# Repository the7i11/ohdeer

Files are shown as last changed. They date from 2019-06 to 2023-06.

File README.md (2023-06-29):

# Oh Deer!

A non-profit and open source project, with the goal to develop a device to frighten deer and other ferral animals.

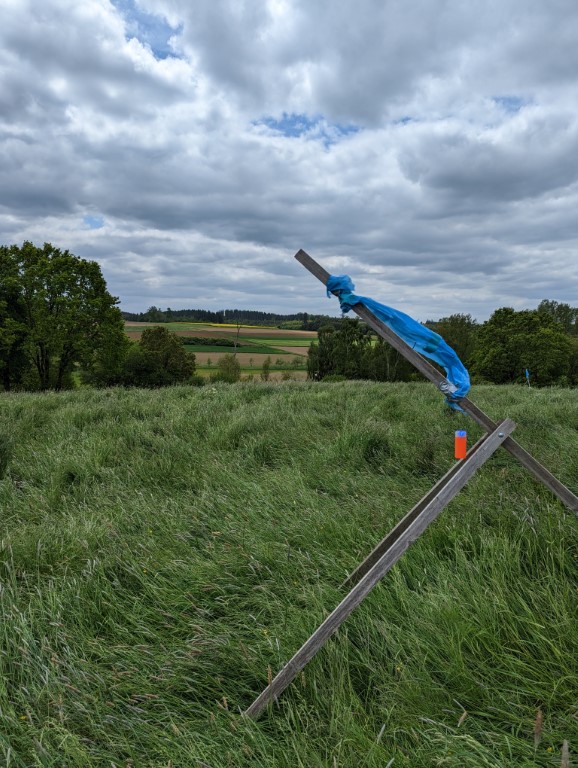
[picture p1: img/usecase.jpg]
Use case


## About this project

Every spring, usually around May, deer will give birth to their fawns. Still not being able to run away from potential predators, those fawns will rely on their camouflage and remarkable abscence of any kind of scent to survive. Early in the morning, still before sunrise, their mothers will lay them down in high grass, where they hopefully won't be discovered, to pick them up again at dawn.

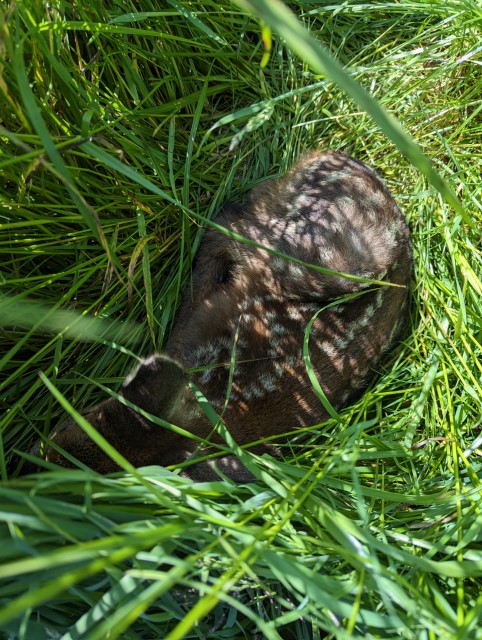
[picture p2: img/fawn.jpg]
Fawn in grass


Unfortunately, this time of the year does overlap with farmers having to mow their meadows. As you might guess, the tractor does not really care about good camouflage at all - so when the fawns will instinctively just put their head down, being mowed over will result in certain death.

Of course, farmers are obligers to take precautions, but if only half of all farmers would actually take what is required, the [...]
At least in Germany, hunters will support the farmers to prevent fawns from death by mower, sometimes by taking multiple precautions. Hunters will walk through the meadows in tight grids, fly over them using drones and thermal imaging technology and (that's what this project is about) take measures so the deer won't put their fawns in the grass in the first place.

Taking a commercial product as an example, we developed a device, that is placed in the meadows the day befor the farmer want's to mow it. The loud beeping and random, bright, blue blinking of the device will (hopefully) scare mother deer so much, that they won't put their fawns in this field specifically.

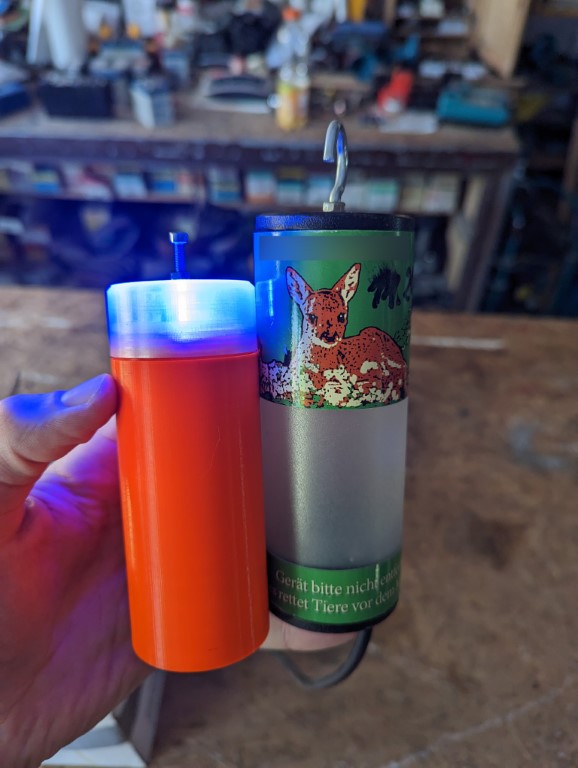
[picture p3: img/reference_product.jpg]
Oh deer


The reference product that we used for the past years did cover our needs, but was way to expensive for the ammount we required. For larger meadows, you'll need around 10-15 of those tubes, costing a hefty four-digit ammount of money that we have to largely pay out of our own pockets. 

This is why we started to develop our own, low-cost variant of this. Apart from you having to assemble it manually, we do have many advantages over the commercial one:

- Being open source means you can modify it to fit your specific needs
- We come in at less than a tenth of the price of the commercial one
- The conveniance in handeling of Oh Deer is far higher, mostly because of the integrated battery/charger
- The LED is way brighter and does have a seemingly random pattern
- In our next iteration, the buzzer will be much louder, covering a higher radius

In case you want to build your own devices from this, you should find everything required within this repository.

## First / Second iteration

As a first draft, I developed the project around the STM8F103 microcontroller. Back in the day, it way readily available and cheap. 
The second iteration will be using a Risc V controller from CHT (CH32V003), which has become famous for being one of the cheapest general-purpose µCs there is.

## Getting started

To actually build the devices on your own / contribute to the project, please follow the guides for each HW iteration:

- [1. Iteration](doc/1.0_Getting_Started.md)
- [1. Iteration](doc/2.0_Getting_Started.md)

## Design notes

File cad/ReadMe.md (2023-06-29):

# 3D-Printed Case

For the sake of simplicity, the case is coming directly out of a 3D-Printer.
If you don't have one on you own, you might wan't to ask someone who does.
As with the other hardware, I (currently) cannot provide them to anyone I don't know personally.

## How to print

Printing in PETG will generally have a higher weather resistance than PLA. However, PLA will not immediately dissolve in rain - it can withstand even more than a year ouside without turning into compost.

### Lid

- `lid.stl`
- Printed transparently
- Extrusion factor bumped up by 3%-5% (better transparency)

### Base Case

- `base_case.stl`
- Printed in bright orange to be easily visible in the green grass

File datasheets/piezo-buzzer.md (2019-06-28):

# Available data

- 3-24 V
- Alarm Durchmesser: 22mm/0,86"
- Alarm Höhe: 10mm/0,39”
- 2 montage Löcher abstand: 30mm/1,18"
- 2 drähte länge: 90mm/3,54"
- Summer Typ: Piezoelektrischen
- Schalldruckpegel 95 dB
- Rate Spannung: 12 V DC
- Betriebs Spannung: 3-24 V
- Max Strom Bewertung 10mA
- Frequenz 3900±500Hz
- Stick Methode: Stick Schaltung Gebaut in Montage Löcher
- Sound: "Di" Kontinuierliche

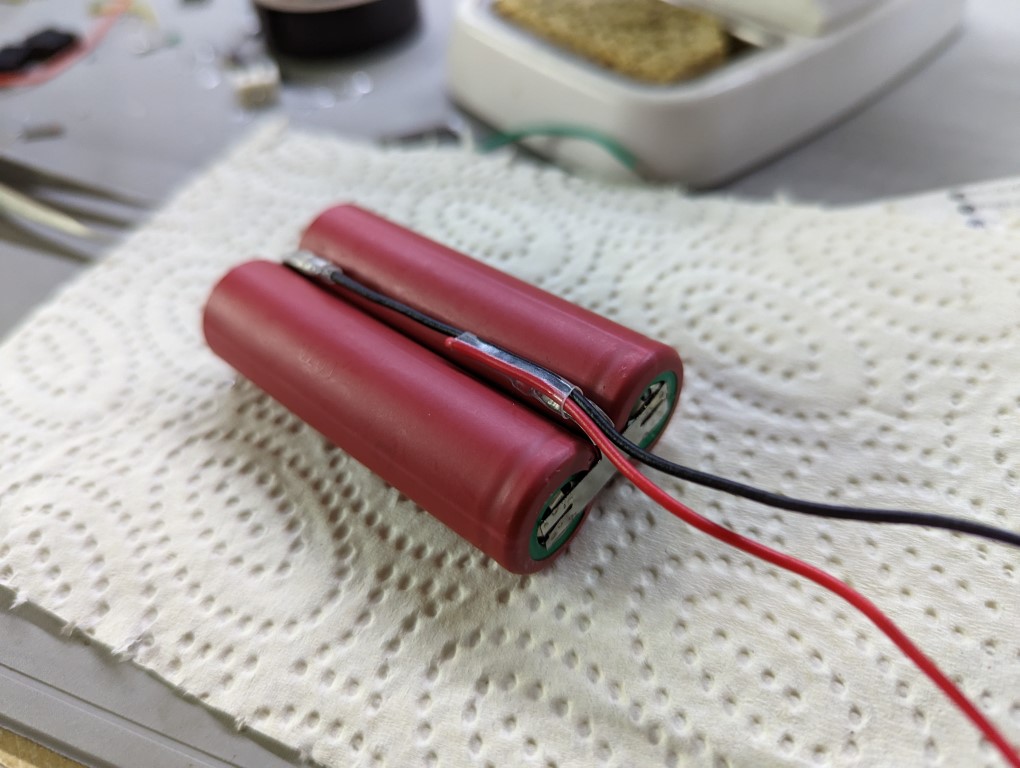
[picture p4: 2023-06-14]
img/battery_pack.jpg

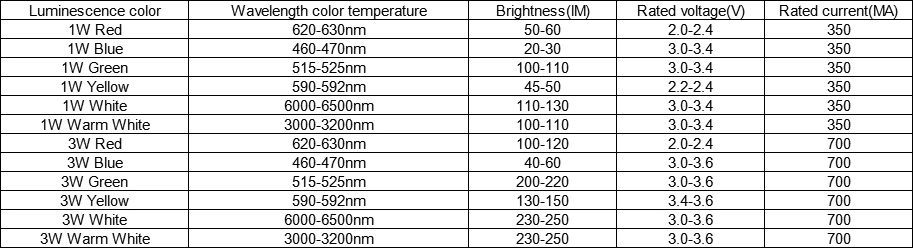
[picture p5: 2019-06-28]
datasheets/LED-2.webp

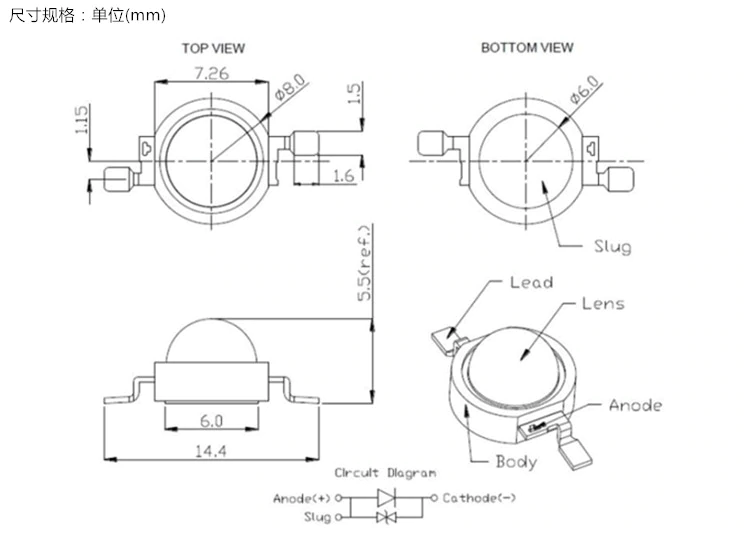
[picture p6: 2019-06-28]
datasheets/LED-1.webp

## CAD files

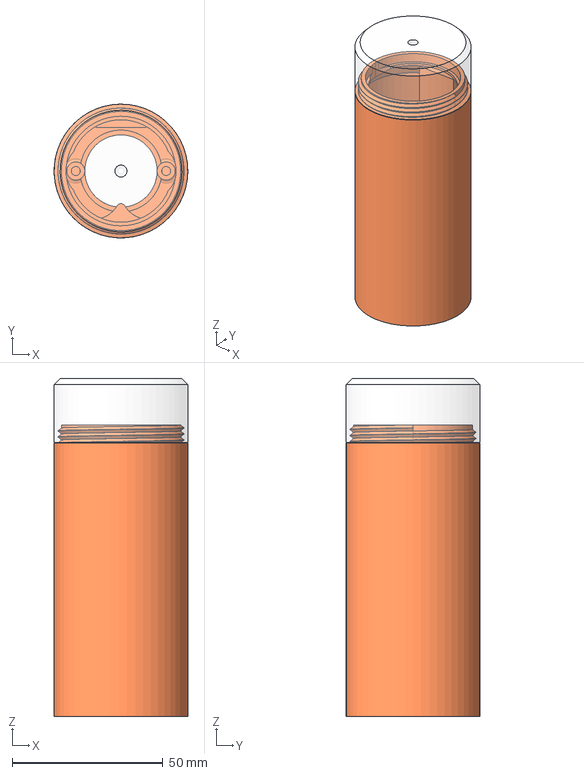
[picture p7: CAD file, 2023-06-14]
cad/base_case.FCStd
44.4 x 44.4 x 112.2 mm
case
Lid

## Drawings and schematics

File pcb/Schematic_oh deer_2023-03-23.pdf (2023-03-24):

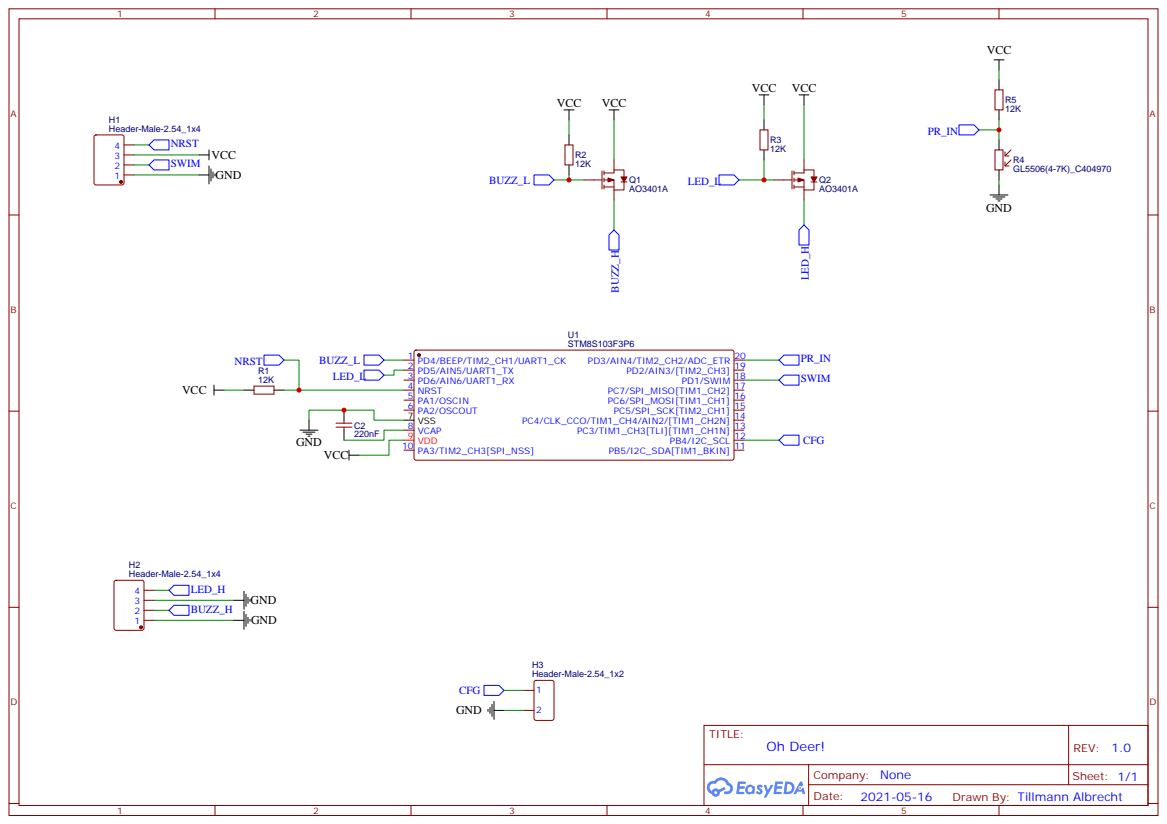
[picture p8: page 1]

Drawn By: Tillmann Albrecht

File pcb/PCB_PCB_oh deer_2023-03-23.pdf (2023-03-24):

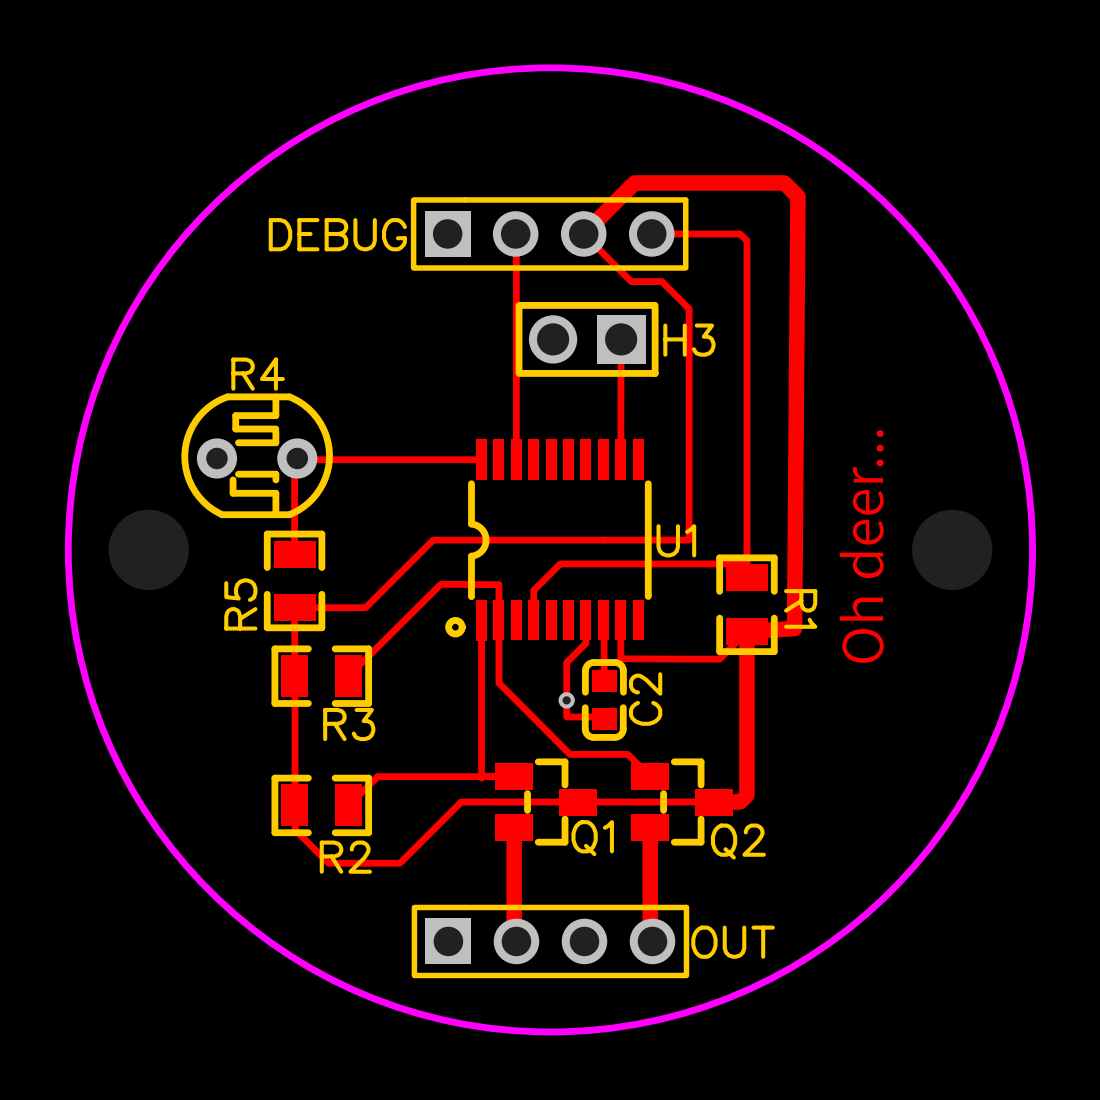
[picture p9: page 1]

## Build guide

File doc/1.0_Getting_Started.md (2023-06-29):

# Getting Started - First iteration

## Hardware requirements

- [PCB](https://oshwlab.com/tillmann95/oh-deer)
- [ST-Link V2](https://www.st.com/en/development-tools/st-link-v2.html) (or Mini) + 4 Socket-to-Socket Jumper cables
- [3D printed Case](../cad/ReadMe.md)
- 1 - 2 Generic 18650 (Li-Ion) cells
- _(optional)_ A spot welder & some nickle strips
- [Battery Protection module](https://www.reichelt.de/entwicklerboards-ladeplatine-fuer-3-7v-li-akkus-usb-c-1a-debo1-3-7li-1-0a-p291398.html)
- Piezo buzzer
- Some generic M3 screws for assembly

## Software requirements

- Visual Studio Code
- PlatformIO plugin for VS Code
- ST-Link drivers

## PCB Assembly

- Do detailed assembly guide yet
- Figure this out on your own using the [PCB drawing](../pcb/PCB_PCB_oh%20deer_2023-03-23.pdf) and [circuit schematic](../pcb/Schematic_oh%20deer_2023-03-23.pdf)

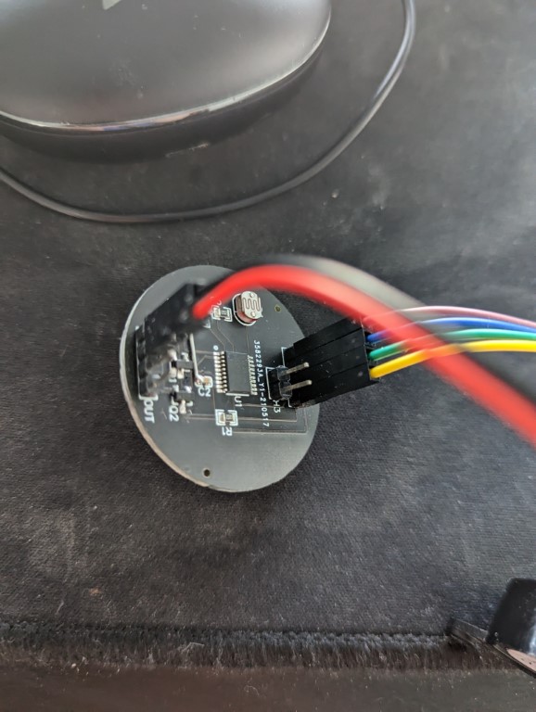
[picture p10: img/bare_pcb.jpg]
bare pcb


## Preparing the flashing/debugging

Connect the following pins from the ST-Link V2 to the PCB. You should find their labels on the device/PCB:

- GND
- SWIM
- RST
- 3V3 (or 5V, both will work)

By using 3V3, the buzzer is somewhat easier to bear during development. Even taping it shut will only dampen the noise so a somewhat bearable level.

## Compiling & FW download

After opening this project in PlatformIO, you can just hit the "Upload" button from inside PlatformIO. Now the device should already be blinking & beeping.

## Mounting the buzzer

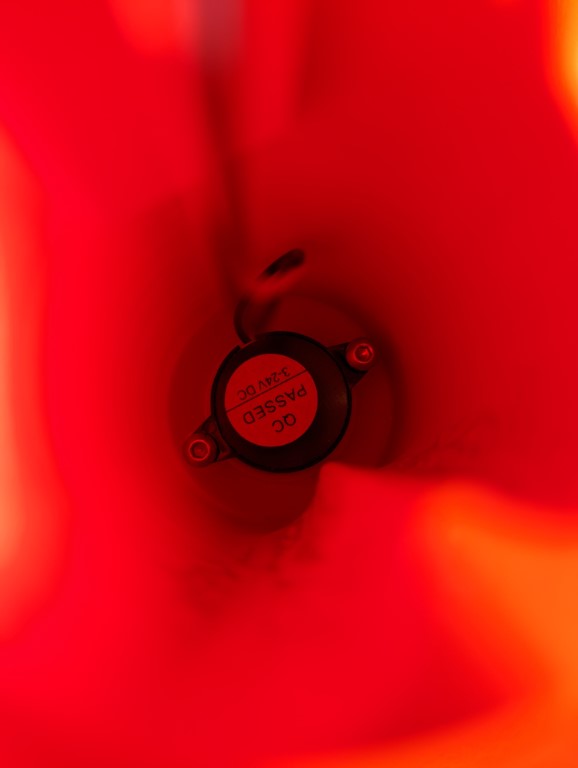
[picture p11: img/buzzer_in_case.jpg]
Buzzer in case


The buzzer gets screwed in using M3  screws (5mm - 8mm length).

This can be a bit fiddly. If you bend the wires straight before inserting, you might have an easier time.

## _(optional)_ Battery pack assembly

The _proper_ way to connect 18650 cells to a pack and connect wires to them is using a spot welder:

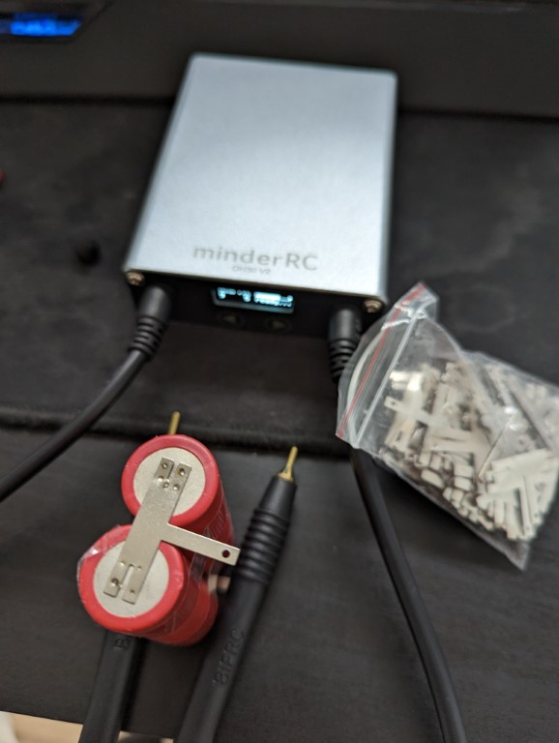
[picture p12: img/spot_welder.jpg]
spot welder


This makes sure that the delicate cells don't overheat and explode. _It is possible_ to solder directly to the pads, but it's a pain in the ass and I can only **strongly** discurage you from trying this. However, I can't tell that I've never done this myself in a time of great need, but that's up to you.

Connect the cells in parallel for higher capacity. It's totally fine to use old, recycled cells. With one cell of ~2500mAh capacity left, you'll still get a battery life of about a week.

The case is designed so that the two batteries should touch each other to fit in, so keep that in mind and make sure that the cell remain perfectly parallel when welding them. 

**WARNING:** Make sure that the two leads don't short out!
The cells currently don't have short-circuit protection and might blow up if shorted. 

## Battery mounting

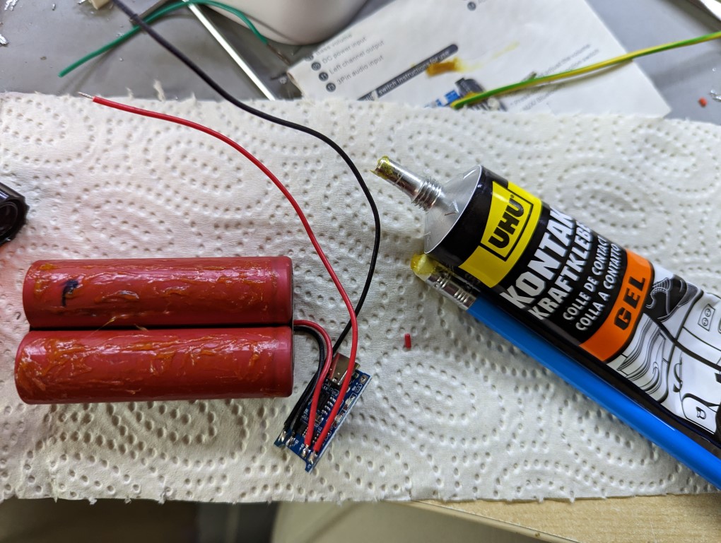
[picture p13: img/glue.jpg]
Battery pack mounting


Connect the "raw" battery (-pack) to the charge/protection module. The modules usually have terminals labeled `B+` and `B-` for the cell connections.

Remember to connect cables to the module's output, that are still long enough to be connected to the Oh deer! PCB once the protection module is glued in place.The output wires are meant to receive a dupont connector, so you can (dis-) connect them easily. This also is used to trn the whole thing on or off.

The cells and the module itself are glued to the base case using generic contact/all purpose glue. You can use epoxy or super glue, but be aware that some of those harden in an exothermic way, which might actually overheat your cells.

## Final steps

Solder the buzzer to the main PCB. Now you can check if everything is working as intended!

Connect the protection board to the main PCB. The LED should now start flashing and the buzzer should start beeping.

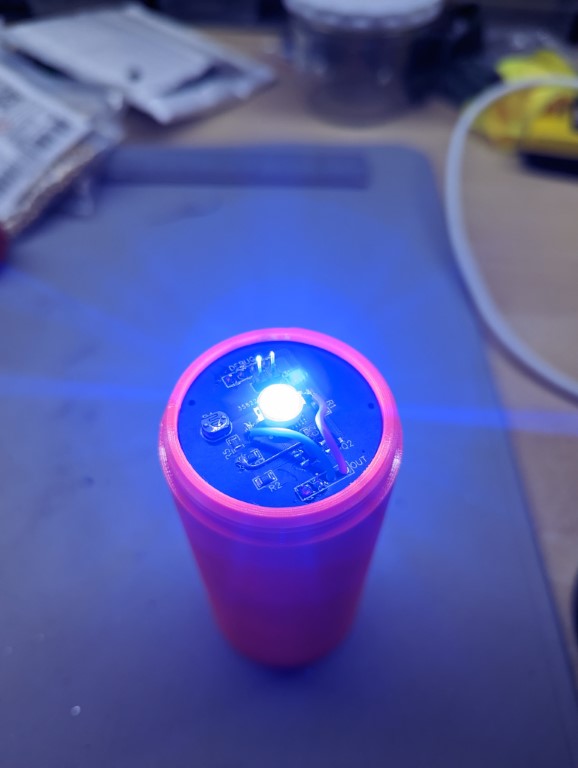
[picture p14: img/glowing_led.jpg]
working device


If everything works as intended, you're basically done!

Disconnect the power leads from the PCB to turn it off. Once you want to use it, connect them, put the main PCB into the base case and screw on the lid.

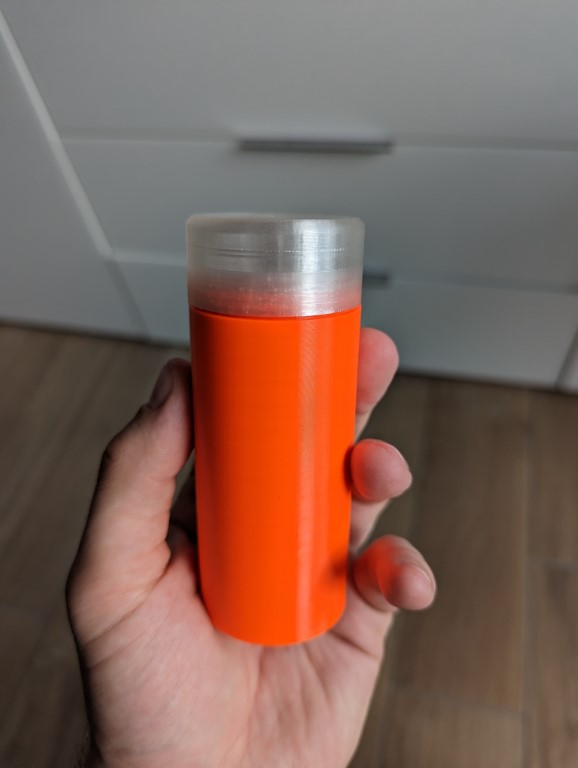
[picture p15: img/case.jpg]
whole device


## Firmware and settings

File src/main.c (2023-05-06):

/*
  The main task of this? Blinking and beeping in a somewhat obscuring manner.
  The device will beep and blink in short bursts with a pattern that'll vary every time.
  Which pattern will be used is chosen for the LED and the buzzer individually.
  Patterns are described in the look up table below.
*/

/*----------------------------------------------------------
    Defines
----------------------------------------------------------*/

#define LED_PIN PIN5
#define BUZZ_PIN PIN4
#define PR_PIN PIN3
#define CONFIG_PIN PIN2
#define PORT   sfr_PORTD
#define DELAY_SCALER 1024
#define PATTERN_LENGTH 12

/*----------------------------------------------------------
    Include files
----------------------------------------------------------*/
#include "STM8S103F3.h"

/*----------------------------------------------------------
    Global variables
----------------------------------------------------------*/
uint8_t* pattern[PATTERN_LENGTH][PATTERN_LENGTH] = {
    {51, 19, 124, 33, 39, 173, 194, 143, 61, 175, 203, 59},
    {148, 106, 56, 49, 182, 16, 51, 120, 195, 45, 107, 221},
    {178, 198, 5, 223, 63, 238, 241, 180, 226, 232, 55, 40},
    {43, 186, 115, 75, 250, 73, 3, 130, 184, 150, 117, 9},
    {75, 41, 17, 74, 217, 39, 78, 180, 55, 119, 82, 117},
    {114, 152, 46, 241, 159, 154, 244, 100, 213, 183, 140, 229},
    {36, 1, 203, 37, 43, 11, 163, 66, 72, 227, 136, 24},
    {55, 236, 23, 18, 2, 233, 106, 139, 145, 15, 51, 28},
    {76, 108, 182, 69, 231, 17, 30, 106, 163, 61, 134, 226},
    {248, 195, 86, 116, 31, 234, 58, 236, 27, 17, 75, 255},
    {71, 95, 70, 90, 116, 123, 196, 62, 253, 16, 164, 234},
    {14, 148, 216, 42, 9, 252, 129, 211, 114, 128, 182, 63}
};

uint32_t index = 0;

/*----------------------------------------------------------
    Functions
----------------------------------------------------------*/

void toggle_pin(PORT_t *port, uint8_t pin) {
    port->ODR.byte ^= pin;
}

/* Will return the measured AD value of the photo resistor */
uint16_t read_pr() {
    uint16_t value;
    uint8_t drh = sfr_ADC1.DRH.byte;
    uint8_t drl = sfr_ADC1.DRL.byte;
    value = ((uint16_t)drh << 2  | (uint16_t)drl);
    return value;
}

/* Will return 1 if the CFG jumper is set, otherwise 0 */
uint8_t read_cfg() {
    uint8_t value = 0;
    uint8_t drh = sfr_ADC1.DRH.byte;
    return value;
}

/* Will delay by No-Oping */
void delay(uint8_t units) {
    /*  Yes, this is a stupid nested loop. The max. bit width in the registers is 16 bit,#
        which isn't enough for the delays we're looking at. */
    for (int i = 1024; i>0; i--) {
        for (int j = units; j>0; j--) {
            NOP();
        }
    }
}

void init_GPIO() {
    // Init GPIO.

    // Only output pins are set to 1, all other must be 0
    sfr_PORTD.DDR.byte = 0x0 | LED_PIN | BUZZ_PIN;
    // 
    sfr_PORTD.CR1.byte = 0x0 | LED_PIN | BUZZ_PIN;
    sfr_PORTD.CR2.byte = 0;

    // GPIO used for ADC
    // sfr_PORTD.CR1.byte = 0;
    // sfr_PORTD.CR2.byte = 0;

    // Init ADC
    // Disable Schmitt trigger to save some power
    sfr_ADC1.TDRH.TD = 2;
    sfr_ADC1.TDRL.TL = 0;
    // Switch the ADC on
    sfr_ADC1.CR1.ADON = 1;

    return;
}

void init_AWU() {
    // Measuring the LS clock frequency isn't required, as the timing doesn't need to be exact
    // Selecting the highest time base here, we want the full 30s
    sfr_AWU.TBR.AWUTB = 0xf;
    // Same thing, we're just not allowed to take 0x3f, which is the reset value
    sfr_AWU.APR.APR = 0x3e;
    // Set the AWUEN bit in the Control/status register (AWU_CSR)
    sfr_AWU.CSR1.AWUEN = 1;

    // ENABLE_INTERRUPTS();
}

void main (void) {

    init_GPIO();
    init_AWU();
    read_pr();
    read_cfg();

    toggle_pin(&PORT, LED_PIN);
    delay(255);
    toggle_pin(&PORT, BUZZ_PIN);
    delay(255);
    toggle_pin(&PORT, LED_PIN);
    delay(255);
    toggle_pin(&PORT, BUZZ_PIN);
    delay(255);

    while (1)
    {
        // Do the beepy blinky thing
        for (int i = 0; i < PATTERN_LENGTH; i++)
        {
            toggle_pin(&PORT, LED_PIN);
            delay((uint8_t)pattern[index % PATTERN_LENGTH][i]);
            toggle_pin(&PORT, BUZZ_PIN);
        }
        index++;

        // Go to sleep
        ENTER_HALT();

        // reset wakeup flag
        sfr_AWU.CSR1.AWUF = 0;
        sfr_AWU.CSR1.AWUEN = 1;
    }

}

/*-----------------------------------------------------------------------------
    END OF MODULE
-----------------------------------------------------------------------------*/

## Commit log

2019-09-25 :new: initial KiCad project setup
    [ohdeer.kicad_pcb, ohdeer.sch]
2023-03-24 basic case draft
    [base_case.FCStd]
2023-03-24 Layout & PCB design overview
2023-03-24 added mounts for batteries, buzzer & charger to case
    [base_case.FCStd]
2023-06-14 small geomatric optimization
    [base_case.FCStd]
